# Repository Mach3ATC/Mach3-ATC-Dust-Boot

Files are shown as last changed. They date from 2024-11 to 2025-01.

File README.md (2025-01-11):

I have just completed a Jianken JGL-80 2.2KW ATC upgrade with dockable dust boot. I used this and other websites to give me a great base to start with. One of the issues was the information was fragmented or contained small errors in code. I want to give back to the community by making my entire package available for those that want to embark on a similar adventure. The Mach3 files may have a .pp file extension but are actually Cyprus Basic not pascal. The contents of the .pp files need to be pasted into the appropriate button in Mach3 if required.

This includes:
1. M6 tool change macro;
2. Tool Offset macro (to automatically update tool table);
3. ATC tool 0 (set zero height with tool);
4. Screen set with new ATC page and modified page one so there is no need to go to ATC page for setting up and running programs; 
5. Spread sheet with pin out. (Uses Mach3 with Smooth stepper, C10 board and 2 BOBs);
6. STL files for removable dust boot with 80mm dia router ;
7. Arduino Uno code (for monitoring Router temp /pressure and signal state of clamps). 
8. Mach 3 Brains 
9. Some video/photos of installation/system; and
10. Vectric post processor to handle ATC air seal.

Use at own risk

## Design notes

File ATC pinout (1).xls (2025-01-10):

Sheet: BOB pin out
 | Smooth stepper Port 1 BOB 1 | Smooth stepper Port 2 BOB 2 | Smooth stepper Port 3 C-10 port
 | B= bidirectional O=out I=in
1 |  |  | O
2 | O X PUL | O B Axis PUL | I Tool touch off (index)
3 | O X DIR | O B Axis DIR | I Touch off limit switch (Trig 1)
4 | O Y PUL | B | I Y home switch (Y Home) -P4
5 | O Y DIR | B | I Z home switch (Z home) -P5
6 | O Z PUL | B | I Spindle clamp Open (Trig 2)-P6 -Dsub 2 P6 (#22 from router)
7 | O Z DIR | B | I Spindle clamp Closed (Trig 3)-P7 -Dsub 2 P7 (#11 from router)
8 | O A PUL | O (black) -P1 | I Laser Prox switch (Trig 4) -P8- Dsub 2 P8
9 | O A DIR | O (Blue) -P2 | I Pressure Sensor (Trig 5) -P9 -Dsub 2 P9
10 | E stop | I | I Temp sensor (Trig 6) -P10- Dsub 2 P5
11 | Arc OK | XP45 machine transfer | I
12 | Plasma head crash (A++ limit) | Torch head proximity | I
13 | Y axis Limit | Ohmic prob | I A axis proximity switch (A Home)
14 | Enabled (not used) | O (brown) -P3 | O ATC Air seal Solenoid (Output 7) -P1
15 | Z axis Limit | Plasma Head micro | I X axis proximity switch (X Home)
16 | Not used | O (Green/Yellow) -P4 | O Tool Release (Output 8) -P2
17 | Plasma contact | Router contact | O Tool load (Output 9) -P3
 |  | GND (white) -P5 | GND - green/yellow wire - P12 -Dsub 2 P3
 |  | + 5 V (analog output) | +5V -P11 Dsub 2 P1
 | + 24 V | + 24 V
 | GND 24 V | GND 24 V
 | Plasma contact | Router contact

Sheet: User OEM codes
User OEM Code | I/O | DRO (1000 to 2254) | Button | LED (1000 to 2254) | Label (0 to 255) | Tool value (1 to 253) | Shank | description
Tool change location X |  | 1200 |  |  |  | 1 | 4mm | 1mm ball
Tool change location Y |  | 1201 |  |  |  | 2 | 4mm | 2mm ball
Tool change location Z |  | 1202 |  |  |  | 3 | 1/8 | 1/8 Ball
 |  | 1203 |  |  |  | 4 | 4mm | 1 flute mill
 | O OUTPUT11 |  |  | 1204 |  | 5 | 10mm | Ball
 | O OUTPUT12 |  |  | 1205 |  | 6 | 6mm | Ogee bit
 | O OUTPUT13 |  |  | 1206 |  | 7 | 6mm | V bit
Air seal Solenoid | O OUTPUT7 |  |  | 1207 |  | 8 | 6mm | Ball
Tool release solenoid | O OUTPUT8 |  |  | 1208 |  | 9 | 6mm | 1 flute mill
Tool insert Solenoid | O OUTPUT9 |  |  | 1209 |  | 10 | 12mm | 3 flute end mill
 | O OUTPUT10 |  |  | 1210
Touch off limit switch | I trig 1 |  | 1211 | 1211
Spindle clamp open | I trig 2 |  | 1212 | 1212
Spindle clamp closed | I trig 3 |  | 1213 | 1213
Laser Prox switch | I trig 4 |  |  | 1214
Air pressure low | I trig 5 |  |  | 1215
Spindle temp | I trig 6 |  |  | 1216
 | I trig 7 |  |  | 1217
 | I trig 8 |  |  | 1218
 | I trig 9 |  |  | 1219
 | I trig 10 |  |  | 1220
Tool in spindle |  | 1224
Next tool |  | 1225
Dust Boot X |  | 1226
Dust Boot Y |  | 1227
Dust Boot Z |  | 1228
 |  | 1229
 |  | 1230

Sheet: Plasma pin out
XP45
Signal | Type | Notes | Connector Pin |  | D Sub pinout
Start (start plasma) | Input | Normally open.15 VDC open circuit voltage at START terminals. Requires dry contact closure to activate. | 3 |  | White 1
 |  |  | 4 |  | Black 6
Transfer (start machine motion) | Output | Normally open. Dry contact closure when the arc transfers. 120 VAC / 1 A maximum at the machine interface relay. | 12 |  | Grn/Yel 2
 |  |  | 14 |  | Blue 7
Voltage divider | Output | Divided arc signal of 20:1, 21.1:1, 30:1, 40:1, 50:1 (provides a maximum of 16 V). | Black 5 (-)
 |  |  | White 6 (+)
Ground | Ground |  | 13 |  | Brown 3
THC
TIP + |  | Arc_Div + | Brown 1 |  | white 4
TIP - |  | Arc_Div - | Black 6 |  | Black 8
Ground |  |  | Green 4 |  | Grn/Ylo 5
24V |  |  | Yellow 5 |  | Blue 9
Ohmic sensor | PNP output
BOB GND | To | Relay 14 |  | Work piece | Red
BOB P11 | To | Relay 13 |  | Plasma tip | Blue
 |  | Yellow to Relay A1
 |  | GND to Blue to Relay A2
 |  | +24V to Brown 24 V
Proximity Sensor | NPN NC |  | NPN NO
BOB GND | To | Relay 14 | BOB GND | To | Relay 14
BOB P13 | To | Relay 13 | BOB 5v | To | Relay 13
 |  | Black to Relay A1 |  |  | Black to Relay A1
 |  | GND to Blue to Relay A2 |  |  | GND to Blue
 |  | +24V to Brown 24 V |  |  | +24V to Brown to Relay A2
Proximity Sensor 5V C10 board
Brown to 5V
Black to input pin
Blue to board ground
Jumper on board to PULL UP

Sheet: ATC
Automatic tool changer | speed | Power | Collet
JGL-80/2.2R24-20 (https://www.alibaba.com/product-detail/Jianken-JGL-80-2-2kw-24000rpm_62209807294.html) | 24001 | 2.2KW | ER20

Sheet: Router Pin out
HOUSE | L1 | L2 | Ground |  | ROUTER | 1 | 2 | 3 | 4
 | BLACK | RED | Green |  |  | BLUE | RED | BLACK | YELLOW/Green
INVERTER | R | S | Common Ground |  |  | U | V | W | Common GROUND
BOB | SPINDLE | CONTROL | -24 | 24 | +(0-10V) | GROUND
INV CONTROL | FOR- X1 | DCM-CM |  |  | VI -AI | ACM-GND
 |  | Old |  |  |  | New E550
Spindle control |  | P0000 | Parameter Lock |  |  | F0.00 | 1
 | 1 | P0001 | Source of command |  |  | F0.01 | 0
 | 1 | P0002 | source of operating freq |  |  | F0.04 | 400
Notes | 400 | P0003 | Main Frequency |  |  | F0.05 | 10
 | 400 | P0004 | Base Frequency |  |  | F0.06 | 10
 | 400 | P0005 | Max operating freq |  |  | F0.12 | 400
 | 2.5 | P0006 | lntermidiate Freq |  |  | F0.13 | 220
 | 0.5 | P0007 | Min Frequency |  |  | F1.04 | 400
 | 220 | P0008 | Max. Voltage |  |  | F1.08 | 11
 | 13 | P0009 | Intermediate Voltage |  |  | F2.19 | 1
 | 6.5 | P0010 | Min Voltage
 | 120 | P0011 | Freq lower Limit
 | 10 | P0014 | Accel time
 | 10 | P0015 | Decel time
 | 8 | P0041 | Carrier Frequency
 | 0 | P0070 | Analog input
 | 20 | P0071 | Analog Filter constant
 | 350 | P0072 | Low Analog Freq
 | 120 | P0073 | High Analog Feq
 | 220 | P0141 | Motor voltage
 | 10 | P0142 | Motor Current
 | 2 | P0143 | Motor Poles
 | 3000 | P0144 | Motor Revolution
JGL-80/2.2R24-20

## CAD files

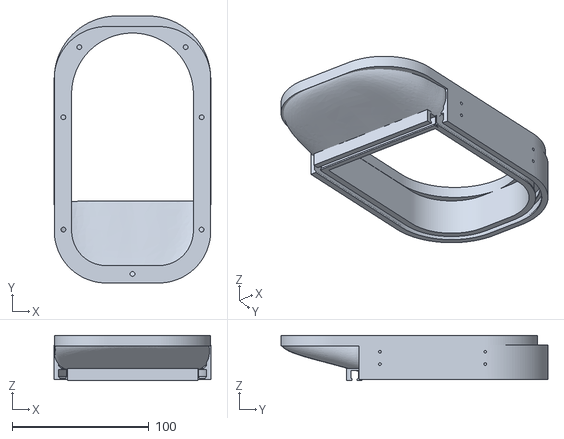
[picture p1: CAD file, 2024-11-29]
Bottom.stl
114.3 x 195.0 x 32.9

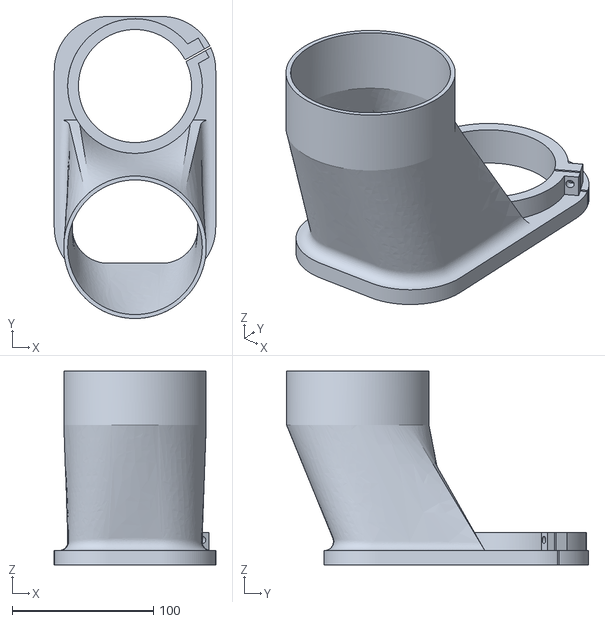
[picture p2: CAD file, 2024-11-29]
Top.stl
114.3 x 213.7 x 137.2

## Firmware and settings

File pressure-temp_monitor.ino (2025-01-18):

// Main presure transducer
// This subroutine ensure pressure is within range and a delay is added to avoid nuisance signals due to transient pressure spikes  
// If ANALOG voltage to "IN" pin A0 are under 2.2 (84 PSI) and above 2.6 (105 PSI) volts for more than 1 sec 
// then OUTPUT pin 12 is turned on (HIGH), 
// IN/OUT pins, voltage and time are variables that can to be adjusted.
// The voltage is set based on the characteristics of the tranducer 
//#define A0 A0
//#define A1 A1
#include <Wire.h>
#include <LiquidCrystal_I2C.h>
#include <Ewma.h> // Library that contains Exponentially Weighted Moving Average filter
// variables for pressure trigger
long PressureOutOfLimitTime = 0; // Variable to keep track of the time the PressureOutOfLimit  has been on
boolean isPressureOutOfLimit  = false; // Flag to check if PressureOutOfLimit  is currently on
// variables for LCD pressure readout
int PressureSensor = 0;
int TempSensor = 0;
int LCDPSI = 0;
int A0Voltage = 0;
int RelayDelay = 0;
//variables for Thermistor
// Watch video in the following link https://www.circuitbasics.com/arduino-thermistor-temperature-sensor-tutorial/
//(https://www.thinksrs.com/downloads/programs/therm%20calc/ntccalibrator/ntccalculator.html)
Ewma adcFilter1(0.1);   // Less smoothing - faster to detect changes, but more prone to noise
//Ewma adcFilter2(0.01);  // More smoothing - less prone to noise, but slower to detect changes
int OverTempOutPin = 11; // pin to send overtem signal to out pin 11 
int ThermistorPin = A1;//input pin A1
int Vo;
float R1 = 10000;
float logR2, R2, T, Tc, Tf;
float c1 = 1.123321447e-03, c2 = 2.361026530e-04, c3 = 0.7181364528e-07;//values are from Thermosister calculator 
LiquidCrystal_I2C lcd_1(0x27,16,2);  // run ic2_scanner sketch and get the IC2 address, which is 0x27 in my case,it could be 0x3f in many cases

void setup() {
// setup for pressure trigger 
  pinMode(12, OUTPUT); // Sets the digital pin 12 as output (for the PressureOutOfLimit )
  pinMode(A0, INPUT); // Sets the analog pin A0 as input (for the Pressure transducer)
// setup for LCD pressure readout
  lcd_1.init();     
  lcd_1.backlight();
  lcd_1.begin(16, 2);
  //pinMode(A0, INPUT);
  lcd_1.setCursor(0, 0);
  lcd_1.print("PSI:");
  lcd_1.setCursor(8, 0);
  lcd_1.print("MPa:");
  lcd_1.setCursor(0, 1);
  lcd_1.print("Rtr Temp:");
 //setup for Thermistor readout (Line 35-42 are to set the LCD screen for bothtemp and press display)
  pinMode(A1, INPUT);
  pinMode(11, OUTPUT);
  lcd_1.print("C");
}


void loop() {
// loop for pressure trigger 
  int sensorValue = analogRead(A0); // Reads the value from the potentiometer
  float voltage = sensorValue * 5.0 / 1023.0; // Converts the value to voltage
  
// Check if the voltage is under 2.1 or over 2.6 volts. The || separates the voltage checking operation above and below the voltage.
  if (voltage <= 2.1 || voltage >= 2.6) {
    if (!isPressureOutOfLimit ) { // If the PressureOutOfLimit  is not already on, record the current time
      PressureOutOfLimitTime = millis();
      isPressureOutOfLimit  = true;
    } else if (millis() - PressureOutOfLimitTime >= 1500) { // PressureOutOfLimit  has been on for more than 1.5 second
      digitalWrite(12, HIGH); // Turn on the Pressure relay
    }
  } else {
    isPressureOutOfLimit  = false; // Reset the PressureOutOfLimit  on flag
    digitalWrite(12, LOW); // Turn off the pressure relay
  }
  // Loop for LCD pressure readout
PressureSensor = analogRead(A0);
  delay(500); // Wait for 500 millisecond(s)
  LCDPSI = map(PressureSensor, 102, 921, 0, 200);//converts voltage to PSI
  lcd_1.setCursor(4, 0);
  lcd_1.print (LCDPSI);
  lcd_1.setCursor(12, 0);
  lcd_1.print ((LCDPSI)*0.00689476);// converts PSI to Mpa)
 
  //Loop for Thermistor  
   int raw = analogRead(ThermistorPin); // Raw reading
   float filtered1 = adcFilter1.filter(raw); // uses EWMA filter 
Vo = filtered1; //Takes the filtered value to use in the formula
 //Vo = analogRead(ThermistorPin); Old code before filter
  R2 = R1 * (1023.0 / (float)Vo - 1.0);
  logR2 = log(R2);
  T = (1.0 / (c1 + c2*logR2 + c3*logR2*logR2*logR2));
  Tc = T - 273.15;
  Tf = (Tc * 9.0)/ 5.0 + 32.0; 
  
  lcd_1.setCursor(9, 1); //temp to LCD
  //lcd_1.print("Temp = ");
  lcd_1.print(Tc);   
  //lcd_1.print(" C");

if (Tc > 48) {   // temp setting in deg C that triggers output to turn on
digitalWrite (OverTempOutPin, HIGH);
}
else {
digitalWrite (OverTempOutPin, LOW);
}
  delay(1500);            
  //lcd_1.clear();
}
